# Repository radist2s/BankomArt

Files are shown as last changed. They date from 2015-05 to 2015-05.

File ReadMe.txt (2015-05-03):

  BankomArt
  Project
  ----------------------------------
  Developed with embedXcode

  Project BankomArt
  Created by Александр Баталов on 24.12.14
  Copyright © 2014 Александр Баталов
  License <#license#>

  References
  ----------------------------------

  embedXcode
  embedXcode+
  ----------------------------------
  Embedded Computing on Xcode
  Copyright © Rei VILO, 2010-2014
  All rights reserved
  http://embedXcode.weebly.com

diecimila
atmega328
diecimila.menu.cpu.atmega328

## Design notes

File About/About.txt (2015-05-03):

 	
	embedXcode
	embedXcode+
	----------------------------------
	Embedded Computing on Xcode

	© Rei VILO, 2010-2014
	All rights reserved	
	http://embedXcode.weebly.com/

embedXcode  • Nov 12, 2014 release 232 • Support for Little Robot Friends
embedXcode+ • Nov 18, 2014 release 234 • Stability improvement for Robotis CM

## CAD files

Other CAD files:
Reference/Drawing/banckomart.skp

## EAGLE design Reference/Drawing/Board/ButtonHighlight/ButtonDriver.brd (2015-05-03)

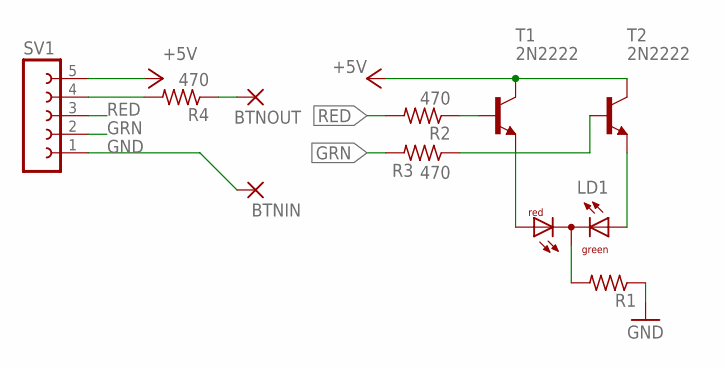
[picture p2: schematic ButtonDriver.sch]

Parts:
BTNIN: 2,54/0,9
BTNOUT: 2,54/0,9
LD1: DUOLED-RG-C; DUOLED-C-5MM
R1: R-US_0207/10; 0207/10
R2, R3, R4: 470; 0207/10
SV1: FE05-1
T1, T2: 2N2222; TO92-EBC-OVAL

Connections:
+5V: SV1.5, T1.C, T2.C
GND: BTNIN.1, R1.1, SV1.1
GRN: R3.2, SV1.2
unnamed: LD1.AR, T1.E
unnamed: LD1.C, R1.2
unnamed: LD1.AX (AG), T2.E
unnamed: R3.1, T2.B
unnamed: R2.1, T1.B
unnamed: R4.2, SV1.4
unnamed: BTNOUT.1, R4.1
RED: R2.2, SV1.3

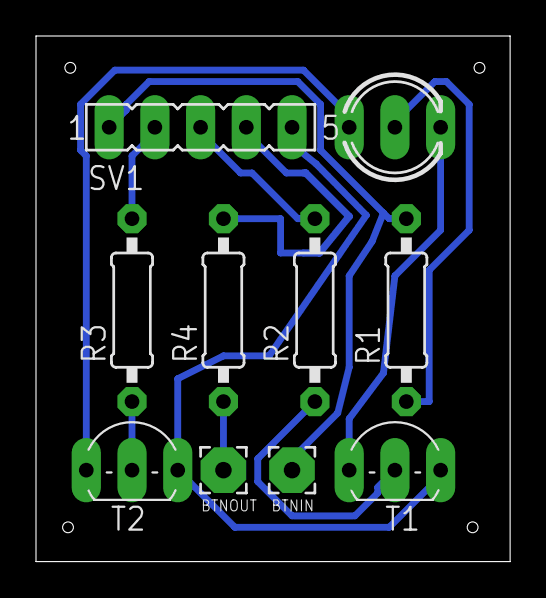
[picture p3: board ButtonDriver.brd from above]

Board: 2 copper layers, 26.3 x 29.2 mm, 10 parts (0 on the bottom side), 11 nets.

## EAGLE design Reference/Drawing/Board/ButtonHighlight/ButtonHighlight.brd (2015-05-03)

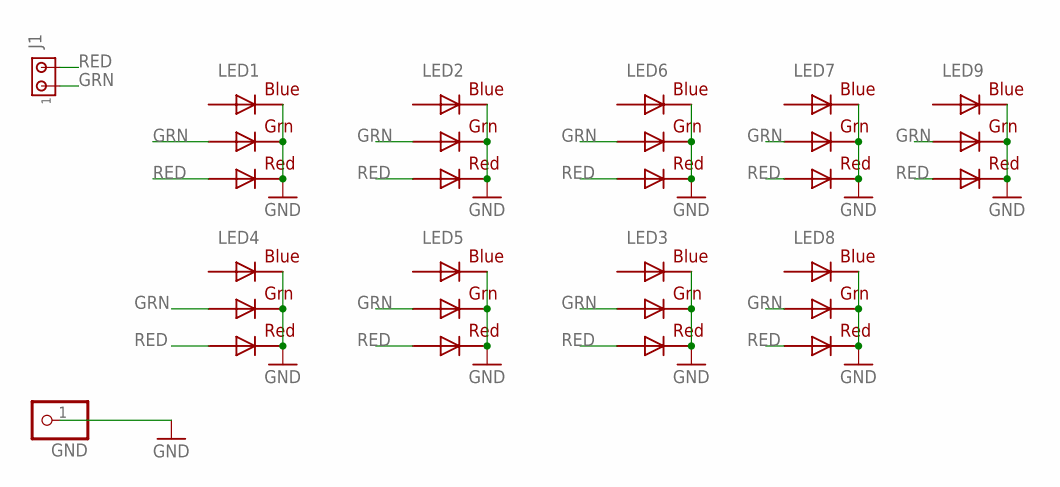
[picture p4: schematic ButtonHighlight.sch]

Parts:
GND: PINHD-1X1; 1X01
J1: MTA02-100; 10X02MTA
LED1, LED2, LED3, LED4, LED5, LED6, LED7, LED8, LED9: RGBLED5050

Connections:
GND: GND.1, LED1.4 (BLUE_C), LED1.5 (RED_C), LED1.6 (GREEN_C), LED2.4 (BLUE_C), LED2.5 (RED_C), LED2.6 (GREEN_C), LED3.4 (BLUE_C), LED3.5 (RED_C), LED3.6 (GREEN_C), LED4.4 (BLUE_C), LED4.5 (RED_C), LED4.6 (GREEN_C), LED5.4 (BLUE_C), LED5.5 (RED_C), LED5.6 (GREEN_C), LED6.4 (BLUE_C), LED6.5 (RED_C), LED6.6 (GREEN_C), LED7.4 (BLUE_C), LED7.5 (RED_C), LED7.6 (GREEN_C), LED8.4 (BLUE_C), LED8.5 (RED_C), LED8.6 (GREEN_C), LED9.4 (BLUE_C), LED9.5 (RED_C), LED9.6 (GREEN_C)
GRN: J1.1, LED1.1 (GREEN_A), LED2.1 (GREEN_A), LED3.1 (GREEN_A), LED4.1 (GREEN_A), LED5.1 (GREEN_A), LED6.1 (GREEN_A), LED7.1 (GREEN_A), LED8.1 (GREEN_A), LED9.1 (GREEN_A)
RED: J1.2, LED1.2 (RED_A), LED2.2 (RED_A), LED3.2 (RED_A), LED4.2 (RED_A), LED5.2 (RED_A), LED6.2 (RED_A), LED7.2 (RED_A), LED8.2 (RED_A), LED9.2 (RED_A)

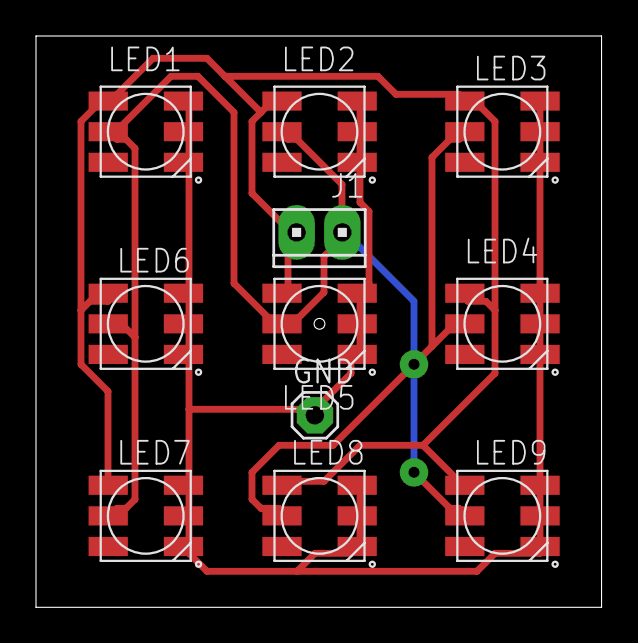
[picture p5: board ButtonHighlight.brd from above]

Board: 2 copper layers, 31.4 x 31.7 mm, 11 parts (0 on the bottom side), 3 nets.

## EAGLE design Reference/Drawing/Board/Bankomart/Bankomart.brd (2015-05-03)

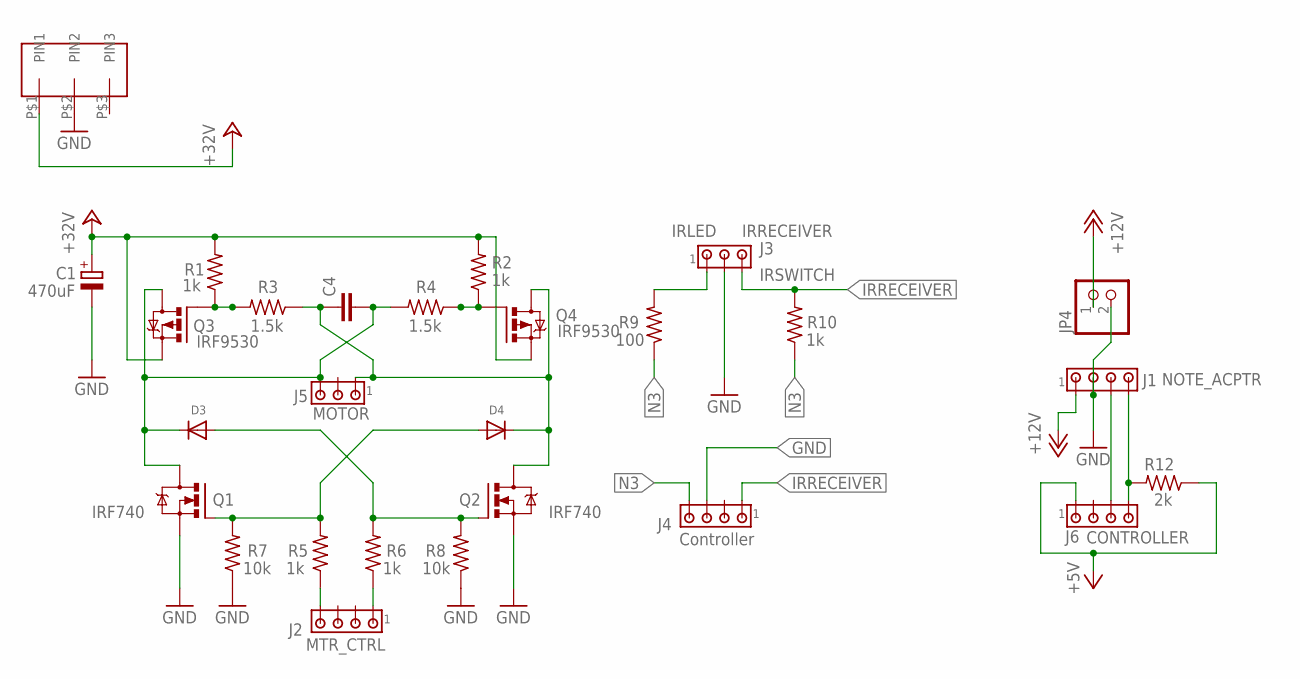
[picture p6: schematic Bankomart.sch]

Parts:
C1: 470uF; E7,5-18
C4: C-EU050-025X075; C050-025X075
D3, D4: DIODEDO-1N4148; DO-1N4148
J1: NOTE_ACPTR; 10X04MTA
J2: MTR_CTRL; 10X04MTA
J3: IRSWITCH; 10X03MTA
J4: Controller; 10X04MTA
J5: MOTOR; 10X03MTA
J6: CONTROLLER; 10X04MTA
JP4: PINHD-1X2; 1X02
Q1, Q2: IRF740; TO220BV
Q3, Q4: IRF9530; TO220BV
R1, R2, R5, R6, R10: 1k; 0207/10
R3, R4: 1.5k; 0207/10
R7, R8: 10k; 0207/10
R9: 100; 0207/10
R12: 2k; 0207/10
U$1: CUSTOM-PIN-3

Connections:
+5V: J6.1, R12.1
+12V: J1.1, JP4.1
+24V: C1.+, Q3.S, Q4.S, R1.2, R2.2, U$1.P$1 (PIN1)
GND: C1.-, J1.2, J3.2, J4.3, JP4.2, Q1.S, Q2.S, R7.1, R8.1, U$1.P$2 (PIN2)
IRLED: J3.1, R9.2
IRRECEIVER: J3.3, J4.1, R10.2
MOTOR_B: J2.1, R6.1
MOTOR_F: J2.4, R5.1
N3: J4.4, R9.1, R10.1
unnamed: Q3.G, R1.1, R3.2
unnamed: C4.1, D4.C, J5.1, Q2.D, Q4.D, R3.1
unnamed: C4.2, D3.C, J5.3, Q1.D, Q3.D, R4.2
unnamed: Q4.G, R2.1, R4.1
unnamed: D3.A, Q2.G, R6.2, R8.2
unnamed: D4.A, Q1.G, R5.2, R7.2
unnamed: J1.3, J6.3
unnamed: J1.4, J6.4, R12.2

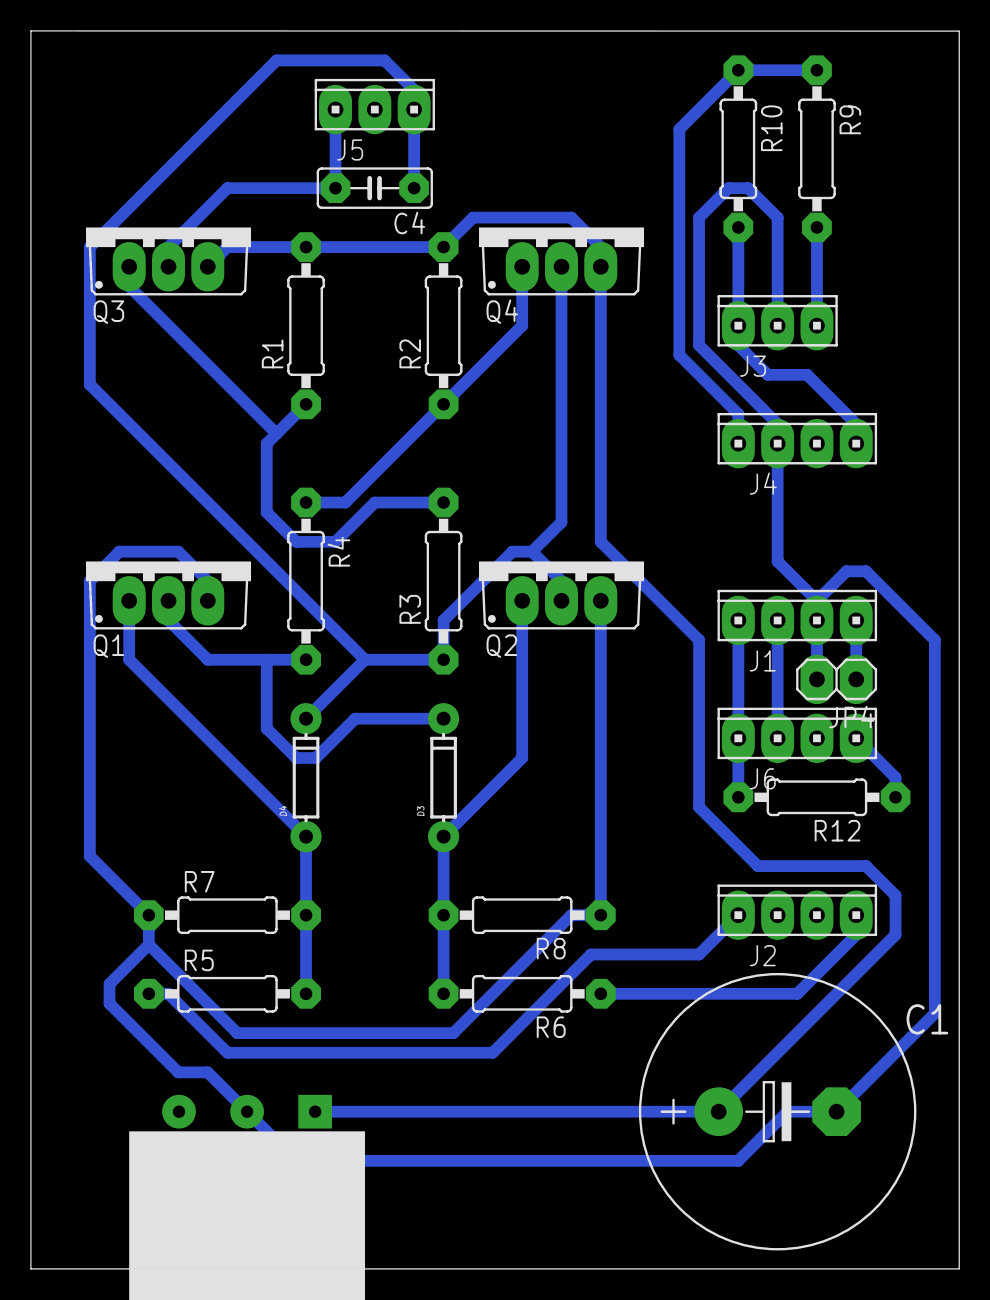
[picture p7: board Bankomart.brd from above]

Board: 2 copper layers, 60.0 x 80.0 mm, 27 parts (0 on the bottom side), 17 nets.

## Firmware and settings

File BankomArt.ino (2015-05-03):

// 
// BankomArt 
//
// Description of the project
// Developed with [embedXcode](http://embedXcode.weebly.com)
// 
// Author	 	Александр Баталов
// 				Александр Баталов
//
// Date			24.12.14 12:25
// Version		<#version#>
// 
// Copyright	© Александр Баталов, 2014
// Licence		<#license#>
//
// See			ReadMe.txt for references
//

#include <Arduino.h>
#include <arduino.h>

#include "LocalLibrary.h"
#include "MotorLibrary.h"
#include <Bounce2.h>

const int
    PAPER_TAKE_BTN_PIN = 10, // 7
    PAPER_TAKE_BTN_HIGHLIGHT_RED_PIN = 12, // 5
    PAPER_TAKE_BTN_HIGHLIGHT_GRN_PIN = 11, // 6
    PAPER_IR_SWITCH_ANALOG_PIN = 0,
    PAPER_IR_SWITCH_ENABLE_PIN = 7, // 11
    PAPER_TAKE_BTN_FORCE_ENABLE_BTN_PIN = 4, // 8
    MOTOR_FWD_PIN = 5, // 9
    MOTOR_BWD_PIN = 6; // 10

const int PAPER_SWITCH_SIGNAL_THRESHOLD = 700;

unsigned long time, ledBlinkTime = NULL;

const float motorRollingSpeed = 1, motorGrabSpeed = 1;

bool
    paperIn = false,
    canTakePaper = false,
    canAcceptNotes = true,
    escrowInProgress = false;

Bounce takePaperBtn = Bounce();
Bounce forceEnableTakePaperBtn = Bounce();

// Define variables and constants
//
// Brief	Name of the LED
// Details	Each board has a LED but connected to a different pin
//

//
// Brief	Setup
// Details	Define the pin the LED is connected to
//

const int
    ESCROW_ACCEPT_CODE = 172,
    ESCROW_REJECT_CODE = 173;

// Accept ESCROW
void acceptNote(bool validatedMode = false) {
    if (validatedMode) {
        setNoteAcceptorOption(ESCROW_ACCEPT_CODE);
    }
    else {
        writeNoteAcceptor(ESCROW_ACCEPT_CODE);
    }
}

// Reject ESCROW
void rejectNote(bool validatedMode = false) {
    if (validatedMode) {
        setNoteAcceptorOption(ESCROW_REJECT_CODE);
    }
    else {
        writeNoteAcceptor(ESCROW_REJECT_CODE);
    }
}

void disablePaperMotorButton() {
    canTakePaper = false;

    digitalWrite(PAPER_TAKE_BTN_HIGHLIGHT_GRN_PIN, LOW);
    digitalWrite(PAPER_TAKE_BTN_HIGHLIGHT_RED_PIN, HIGH);
    
    DEBUG_PRINT("Paper motor Disabled");
}

int takePaper() {
    int error = 0;
    unsigned long time, paperRollingTime, paperGrabTime = NULL, startTime;
    
    digitalWrite(PAPER_IR_SWITCH_ENABLE_PIN, HIGH);
    
    startTime = time = millis();
    
    while (true) {
        int paperInSwitchSignal = analogRead(PAPER_IR_SWITCH_ANALOG_PIN);
        
        if (paperInSwitchSignal < PAPER_SWITCH_SIGNAL_THRESHOLD) { // Paper grabed and rolling
            setSpeed(motorRollingSpeed, -1);
            
            paperRollingTime = time;
            
            if (paperGrabTime == NULL) { // If paper was grabed early
                paperGrabTime = time;
            }
            
            paperIn = true;
            
            if (time - paperGrabTime > 5000) {
                setSpeed(0, -1);
                
                DEBUG_PRINT("Paper jam");

                error = 2;
                
                break;
            }
        }
        else {
            if (paperIn) { // Paper near the exit
                if (time - paperRollingTime > 3000) { // Waite while paper in printer, then stop
                    paperIn = false;
                    setSpeed(0, -1);
                    
                    break;
                }
            }
            else {
                setSpeed(motorRollingSpeed, 1); // Start paper grabing
                paperGrabTime = time;
                
                if (time - startTime > 5000) {
                    setSpeed(0, 1);
                    
                    DEBUG_PRINT("No paper inside");
                    
                    error = 1;
                    
                    break;
                }
            }
        }
        
        time = millis();
    }
    
    digitalWrite(PAPER_IR_SWITCH_ENABLE_PIN, LOW);
    
    if (error) {
        DEBUG_ECHO("Paper taken error: ");
        DEBUG_PRINT(error);
    }
    else {
        DEBUG_PRINT("Paper taken success");
    }
    
    return error;
}

bool grabPaper() {
    int error = 0;
    unsigned long time, startTime;

    digitalWrite(PAPER_IR_SWITCH_ENABLE_PIN, HIGH);
    startTime = time = millis();
    
    while (true) {
        int paperInSwitchSignal = analogRead(PAPER_IR_SWITCH_ANALOG_PIN);
        
        if (paperInSwitchSignal < PAPER_SWITCH_SIGNAL_THRESHOLD) { // Paper grabed
            setSpeed(0, -1); // Stop motor
            
            break;
        }
        else {
            setSpeed(motorGrabSpeed, 1); // Start paper grabing
            
            if (time - startTime > 5000) {
                setSpeed(0, 1);
                
                DEBUG_PRINT("No paper inside");
                
                error = 1;
                
                break;
            }
        }
        
        time = millis();
    }
    
    digitalWrite(PAPER_IR_SWITCH_ENABLE_PIN, LOW);
    
    if (error == 0) {
        DEBUG_ECHO("Paper grabing error: ");
        DEBUG_PRINT(error);
        
        return true;
    }
    else {
        DEBUG_PRINT("Paper grabing success");
        
        return false;
    }
}

void enablePaperMotorButton() {
    DEBUG_PRINT("Paper motor Enabled");
    
    digitalWrite(PAPER_TAKE_BTN_HIGHLIGHT_GRN_PIN, HIGH);
    digitalWrite(PAPER_TAKE_BTN_HIGHLIGHT_RED_PIN, LOW);
    
    canTakePaper = true;
}

void serialEventRead() {
    int sData = readNoteAcceptor();
    
    if (sData == NULL) {
        return;
    }

    DEBUG_ECHO("S_EVENT: ");
    DEBUG_ECHO(sData);
    DEBUG_PRINT("; S_DATA__ESCROW: " + (String)escrowInProgress);


    if (ESCROW_ACCEPT_CODE == sData) {
        escrowInProgress = true;
    }
    else if (ESCROW_REJECT_CODE == sData) {
        escrowInProgress = false;
    }
    // Note accepted
    else if (sData > 0 and sData <= 16) {
        if (escrowInProgress != true) {
            if (canAcceptNotes and grabPaper() == true) {
                acceptNote();
            }
            else {
                canAcceptNotes = false;
                
                rejectNote(true);
                disableNoteAcceptor();
            }
        }
        else if (escrowInProgress == true) { // Escrow completed
            escrowInProgress = false;
            
            DEBUG_PRINT("TRANS_COMPLETE");
            
            enablePaperMotorButton();
        }
    }
    // ESCROW aborted by machine
    else if (sData == 70) {
        
    }
    // Request Startup options
    else if (sData == 192) {
        setupNoteAcceptor();
    }
}

void takePaperBtnRead() {
    takePaperBtn.update();
   
    if (canTakePaper != true) {
        return;
    }

    if (takePaperBtn.read() != LOW) {
        return;
    }
    
    DEBUG_PRINT("Take paper Btn On");
    
    canAcceptNotes = false;
    
    disablePaperMotorButton();
    disableNoteAcceptor();
    
    int errorState = takePaper();
    
    if (errorState == 0) {
        canAcceptNotes = true;
        
        enableNoteAcceptor();
        enableNoteAcceptorESCROW();
    }
    
}

// Add setup code
void setup() {
    DEBUG_SETUP();
    
    setSpeedBegin(MOTOR_FWD_PIN, MOTOR_BWD_PIN);
    
    pinMode(13, OUTPUT);
    pinMode(PAPER_IR_SWITCH_ENABLE_PIN, OUTPUT);
    pinMode(PAPER_TAKE_BTN_PIN, INPUT_PULLUP);

    pinMode(PAPER_TAKE_BTN_HIGHLIGHT_RED_PIN, OUTPUT);
    pinMode(PAPER_TAKE_BTN_HIGHLIGHT_GRN_PIN, OUTPUT);
    
    pinMode(PAPER_TAKE_BTN_FORCE_ENABLE_BTN_PIN, INPUT_PULLUP);
   
    takePaperBtn.attach(PAPER_TAKE_BTN_PIN);
    takePaperBtn.interval(5); // interval in ms
    
    forceEnableTakePaperBtn.attach(PAPER_TAKE_BTN_FORCE_ENABLE_BTN_PIN);
    forceEnableTakePaperBtn.interval(5); // interval in ms
    
    disablePaperMotorButton();
    setupNoteAcceptor();
}

//
// Brief	Loop
// Details	Call blink
//
// Add loop code

void loop() {
    serialEventRead();
    
    takePaperBtnRead();
    
    forceEnableTakePaperBtn.update();
    
    if (forceEnableTakePaperBtn.read() == LOW) {
        enablePaperMotorButton();
    }
    
    time = millis();
    
    if (ledBlinkTime == NULL || time - ledBlinkTime > 500) {
        digitalWrite(13, HIGH);
        ledBlinkTime = time;
    }
    else if (time - ledBlinkTime > 250) {
        digitalWrite(13, LOW);
    }
}

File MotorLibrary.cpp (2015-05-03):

//
//  MotorLibrary.cpp
//  BankomArt
//
//  Created by Александр Баталов on 25.12.14.
//  Copyright (c) 2014 Александр Баталов. All rights reserved.
//

#include "MotorLibrary.h"
#include "LocalLibrary.h"

// Set pins in setSpeedBegin()
int directionPinForward = NULL,
    directionPinBackward = NULL;

int directionPrev = NULL;
float speedPrev = NULL;

void setSpeedBegin(int _directionPinForward, int _directionPinBackward) {
    directionPinForward = _directionPinForward;
    directionPinBackward = _directionPinBackward;
    
    pinMode(directionPinForward, OUTPUT);
    pinMode(directionPinBackward, OUTPUT);
}

void setSpeed(float speed = 1, int direction = 1) {
    speed = max(0, speed);
    speed = min(1, speed);
    
    speed = (int) 255 * speed;
    
    if (direction != directionPrev || speed != speedPrev) {
        digitalWrite(directionPinForward, 0);
        digitalWrite(directionPinBackward, 0);
        
        if (direction > 0) {
            analogWrite(directionPinForward, speed);
        }
        else {
            analogWrite(directionPinBackward, speed);
        }
        
        directionPrev = direction;
        speedPrev = speed;
        
        DEBUG_PRINT("Dir: " + (String)directionPrev + " " + "Speed: " + (String)speedPrev);
    }
}

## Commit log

2015-05-03 Release 1.0
    [banckomart.skp]
2015-05-03 Board circuitry added (Eagle Project)
    [Bankomart.brd, Bankomart.sch, ButtonDriver.brd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]
